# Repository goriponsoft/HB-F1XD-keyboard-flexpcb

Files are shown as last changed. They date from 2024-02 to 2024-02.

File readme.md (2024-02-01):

# HB-F1X series keyboard sheet replacement PCB (Flex PCB version)
Based on the data created by S0urceror, we created a Flex PCB version to replace the keyboard sheet.

Operation has been confirmed on the actual HB-F1XD and HB-F1XV. :-)

## Creative Commons - BY NC - license
This data inherits the license of the original data.

Regarding use outside the scope of the license, GORIPON and GORIPON HARDWARE are not concerned and will follow the original author's judgment.

Please contact the original author sourceror_at_neximus_dot_com for any inquiries.

## Files
The PCB and schematics are made for KiCAD.

In KiCAD you can generate the Gerber files and send them to your PCB manufacturer.

## Components
* 1x PCB
* 1x 0.1mm thick plastic board
* 1x double-sided tape

(Since it is difficult to insert the connector as is, it is necessary to attach a thin plastic plate to the connector contact area.)

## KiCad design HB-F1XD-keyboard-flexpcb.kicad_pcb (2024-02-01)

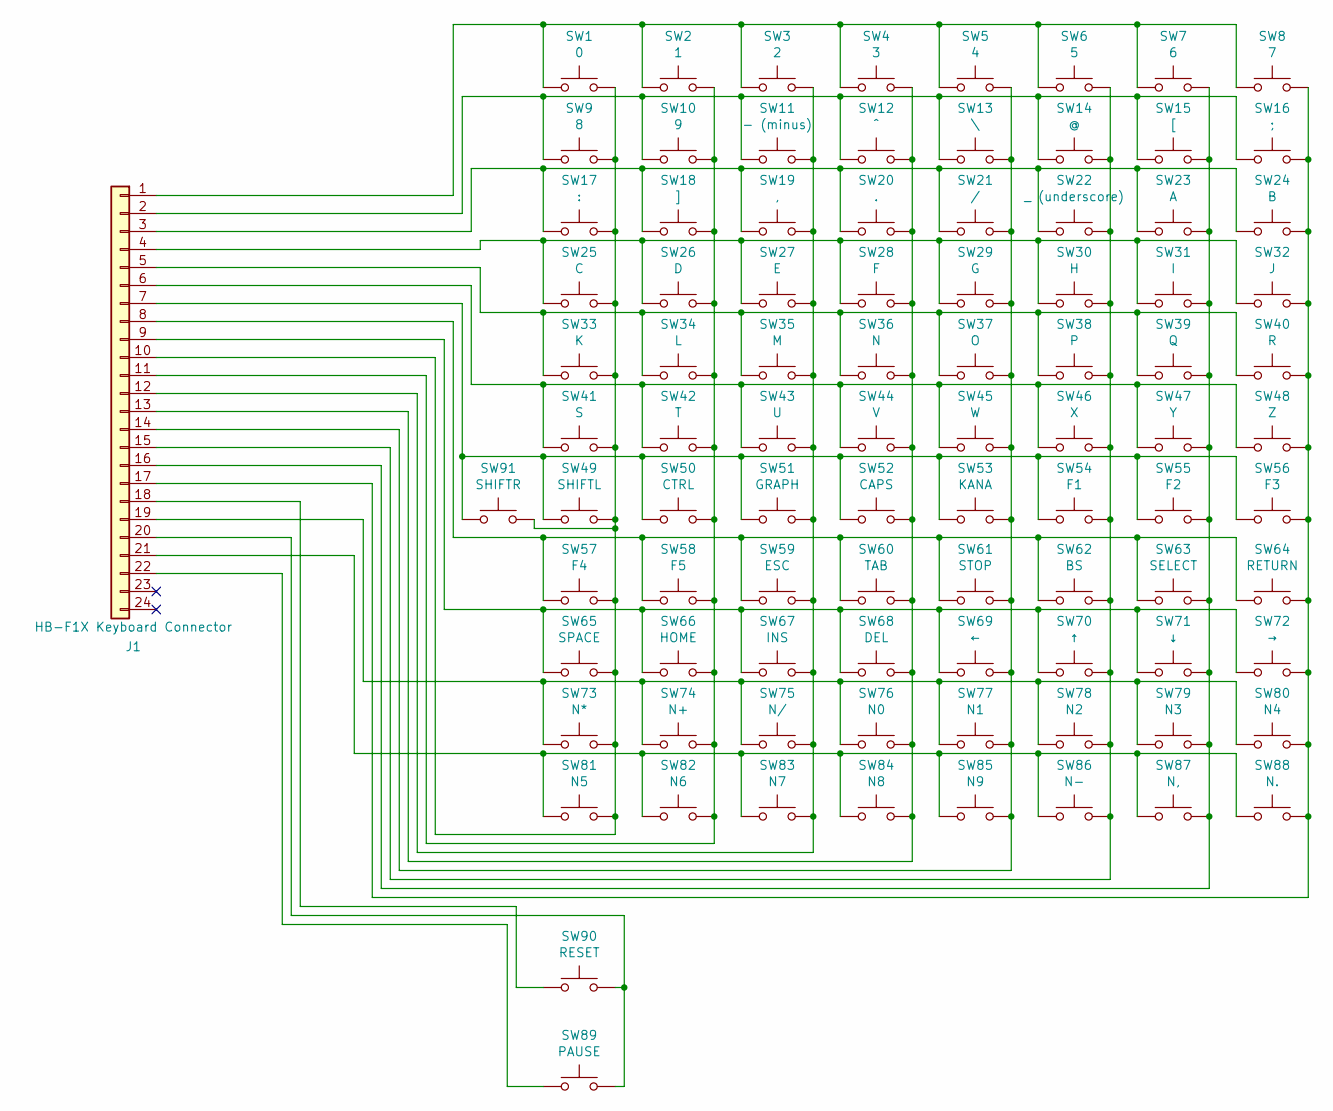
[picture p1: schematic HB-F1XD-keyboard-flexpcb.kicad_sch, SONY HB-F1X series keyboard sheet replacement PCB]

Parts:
J1: HB-F1X Keyboard Connector; edge_connector
SW1: 0; key-diagonal-beauty
SW2: 1; key-diagonal-beauty
SW3: 2; key-diagonal-beauty
SW4: 3; key-diagonal-beauty
SW5: 4; key-diagonal-beauty
SW6: 5; key-diagonal-beauty
SW7: 6; key-diagonal-beauty
SW8: 7; key-diagonal-beauty
SW9: 8; key-diagonal-beauty
SW10: 9; key-diagonal-beauty
SW11: - (minus); key-diagonal-beauty
SW12: ^; key-diagonal-beauty
SW13: \; key-diagonal-beauty
SW14: @; key-diagonal-beauty
SW15: [; key-diagonal-beauty
SW16: ;; key-diagonal-beauty
SW17: :; key-diagonal-beauty
SW18: ]; key-diagonal-beauty
SW19: ,; key-diagonal-beauty
SW20: .; key-diagonal-beauty
SW21: /; key-diagonal-beauty
SW22: _ (underscore); key-diagonal-beauty
SW23: A; key-diagonal-beauty
SW24: B; key-diagonal-beauty
SW25: C; key-diagonal-beauty
SW26: D; key-diagonal-beauty
SW27: E; key-diagonal-beauty
SW28: F; key-diagonal-beauty
SW29: G; key-diagonal-beauty
SW30: H; key-diagonal-beauty
SW31: I; key-diagonal-beauty
SW32: J; key-diagonal-beauty
SW33: K; key-diagonal-beauty
SW34: L; key-diagonal-beauty
SW35: M; key-diagonal-beauty
SW36: N; key-diagonal-beauty
SW37: O; key-diagonal-beauty
SW38: P; key-diagonal-beauty
SW39: Q; key-diagonal-beauty
SW40: R; key-diagonal-beauty
SW41: S; key-diagonal-beauty
SW42: T; key-diagonal-beauty
SW43: U; key-diagonal-beauty
SW44: V; key-diagonal-beauty
SW45: W; key-diagonal-beauty
SW46: X; key-diagonal-beauty
SW47: Y; key-diagonal-beauty
SW48: Z; key-diagonal-beauty
SW49: SHIFTL; key-diagonal-beauty
SW50: CTRL; key-diagonal-beauty
SW51: GRAPH; key-diagonal-beauty
SW52: CAPS; key-diagonal-beauty
SW53: KANA; key-diagonal-beauty
SW54: F1; key-horizontal-beauty
SW55: F2; key-horizontal-beauty
SW56: F3; key-horizontal-beauty
SW57: F4; key-horizontal-beauty
SW58: F5; key-horizontal-beauty
SW59: ESC; key-diagonal-beauty
SW60: TAB; key-diagonal-beauty
SW61: STOP; key-horizontal-beauty
SW62: BS; key-diagonal-beauty
SW63: SELECT; key-diagonal-beauty
SW64: RETURN; key-diagonal-beauty
SW65: SPACE; key-diagonal-beauty
SW66: HOME; key-horizontal-beauty
SW67: INS; key-horizontal-beauty
SW68: DEL; key-horizontal-beauty
SW69: ←; key-diagonal-beauty
SW70: ↑; key-diagonal-beauty
SW71: ↓; key-diagonal-beauty
SW72: →; key-diagonal-beauty
SW73: N*; key-diagonal-beauty
SW74: N+; key-diagonal-beauty
SW75: N/; key-diagonal-beauty
SW76: N0; key-diagonal-beauty
SW77: N1; key-diagonal-beauty
SW78: N2; key-diagonal-beauty
SW79: N3; key-diagonal-beauty
SW80: N4; key-diagonal-beauty
SW81: N5; key-diagonal-beauty
SW82: N6; key-diagonal-beauty
SW83: N7; key-diagonal-beauty
SW84: N8; key-diagonal-beauty
SW85: N9; key-diagonal-beauty
SW86: N-; key-diagonal-beauty
SW87: N,; key-diagonal-beauty
SW88: N.; key-diagonal-beauty
SW89: PAUSE; key-horizontal-beauty
SW90: RESET; key-reset
SW91: SHIFTR; key-diagonal-beauty

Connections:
unnamed: J1.1, SW1.1, SW2.1, SW3.1, SW4.1, SW5.1, SW6.1, SW7.1, SW8.1
unnamed: J1.2, SW9.1, SW10.1, SW11.1, SW12.1, SW13.1, SW14.1, SW15.1, SW16.1
unnamed: J1.3, SW17.1, SW18.1, SW19.1, SW20.1, SW21.1, SW22.1, SW23.1, SW24.1
unnamed: J1.4, SW25.1, SW26.1, SW27.1, SW28.1, SW29.1, SW30.1, SW31.1, SW32.1
unnamed: J1.5, SW33.1, SW34.1, SW35.1, SW36.1, SW37.1, SW38.1, SW39.1, SW40.1
unnamed: J1.6, SW41.1, SW42.1, SW43.1, SW44.1, SW45.1, SW46.1, SW47.1, SW48.1
unnamed: J1.7, SW49.1, SW50.1, SW51.1, SW52.1, SW53.1, SW54.1, SW55.1, SW56.1, SW91.1
unnamed: J1.8, SW57.1, SW58.1, SW59.1, SW60.1, SW61.1, SW62.1, SW63.1, SW64.1
unnamed: J1.9, SW65.1, SW66.1, SW67.1, SW68.1, SW69.1, SW70.1, SW71.1, SW72.1
unnamed: J1.10, SW1.2, SW9.2, SW17.2, SW25.2, SW33.2, SW41.2, SW49.2, SW57.2, SW65.2, SW73.2, SW81.2, SW91.2
unnamed: J1.11, SW2.2, SW10.2, SW18.2, SW26.2, SW34.2, SW42.2, SW50.2, SW58.2, SW66.2, SW74.2, SW82.2
unnamed: J1.12, SW3.2, SW11.2, SW19.2, SW27.2, SW35.2, SW43.2, SW51.2, SW59.2, SW67.2, SW75.2, SW83.2
unnamed: J1.13, SW4.2, SW12.2, SW20.2, SW28.2, SW36.2, SW44.2, SW52.2, SW60.2, SW68.2, SW76.2, SW84.2
unnamed: J1.14, SW5.2, SW13.2, SW21.2, SW29.2, SW37.2, SW45.2, SW53.2, SW61.2, SW69.2, SW77.2, SW85.2
unnamed: J1.15, SW6.2, SW14.2, SW22.2, SW30.2, SW38.2, SW46.2, SW54.2, SW62.2, SW70.2, SW78.2, SW86.2
unnamed: J1.16, SW7.2, SW15.2, SW23.2, SW31.2, SW39.2, SW47.2, SW55.2, SW63.2, SW71.2, SW79.2, SW87.2
unnamed: J1.17, SW8.2, SW16.2, SW24.2, SW32.2, SW40.2, SW48.2, SW56.2, SW64.2, SW72.2, SW80.2, SW88.2
unnamed: J1.18, SW90.1
unnamed: J1.19, SW73.1, SW74.1, SW75.1, SW76.1, SW77.1, SW78.1, SW79.1, SW80.1
unnamed: J1.20, SW89.2, SW90.2
unnamed: J1.21, SW81.1, SW82.1, SW83.1, SW84.1, SW85.1, SW86.1, SW87.1, SW88.1
unnamed: J1.22, SW89.1

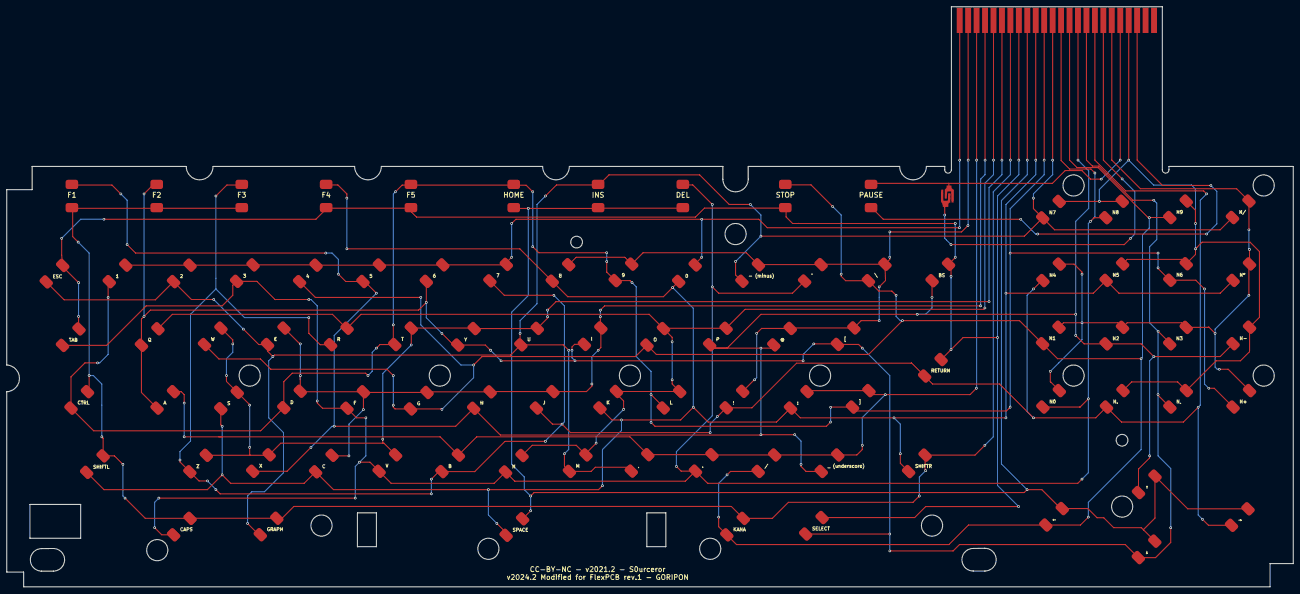
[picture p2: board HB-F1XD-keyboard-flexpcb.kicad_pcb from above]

Board: 2 copper layers, 386.7 x 174.4 mm, 92 parts (0 on the bottom side), 22 nets.

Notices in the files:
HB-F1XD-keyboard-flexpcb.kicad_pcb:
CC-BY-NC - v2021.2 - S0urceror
